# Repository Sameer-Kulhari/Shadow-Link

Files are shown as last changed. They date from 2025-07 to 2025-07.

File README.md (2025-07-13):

# Shadow-Link
A diy high performance Transmitter Module with ELRS support and custom hardware which can transmit data using Sx1280 RF module and ESP-32.
This Transmitter module works on a open source Firmware called ELRS ,which is used in high end transmitters and recievers

# Features :
- 15km + range (LOS)
- 5ms latency
- Oled and RGB
- External Antenna
- ELRS support
- Custom case and Pcb
- Works on Uart
- Works with any ELRS reciever

# Purpose :
- I made this transmitter module for my future projects in which they need a device to transfer data wirelessly , for long range and quickly ,So i made this transmitter module,So I can just send data to this module via Uart and receive on other side using any ELRS reciever.

# Parts Used :
- ESP-32 WROOM
- E28-2G4M27S (SX1280)
- NEOPIXEL (WS2812)
- 0.96" I2C SSD1306
- MP1584 Step Down Regulator

# Images :
**PCB :**
<p align="center">
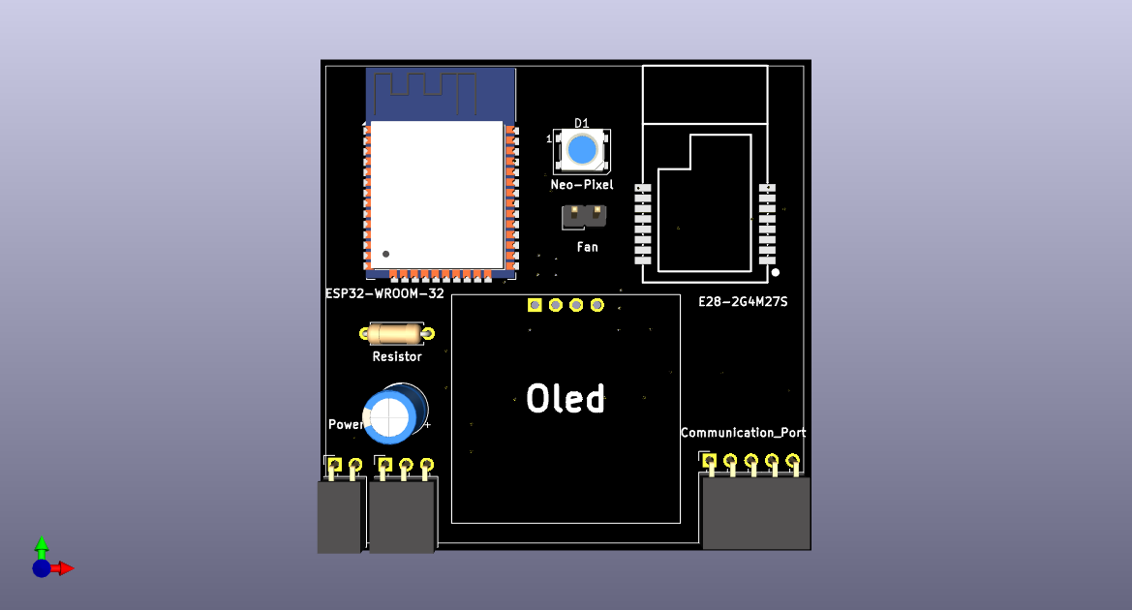
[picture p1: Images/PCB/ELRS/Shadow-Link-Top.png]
  
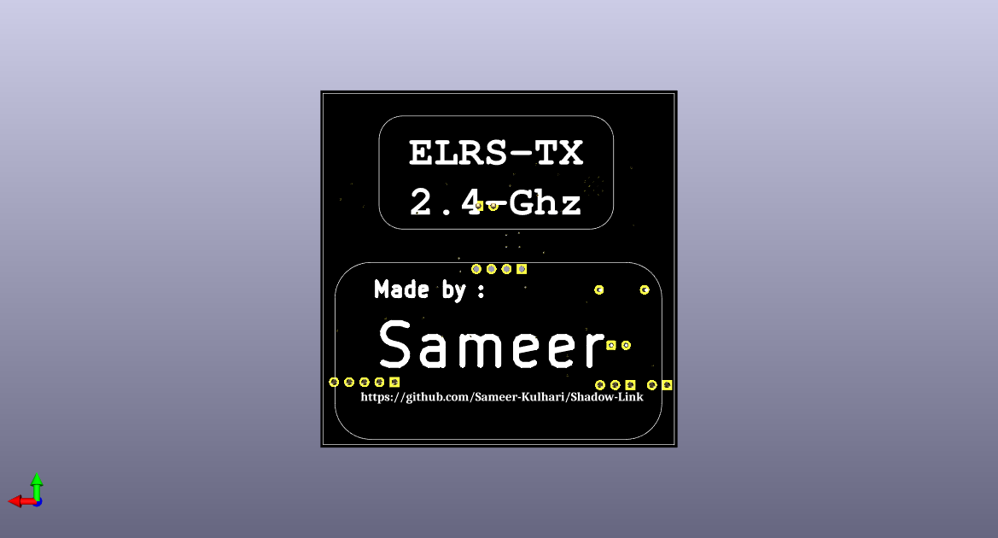
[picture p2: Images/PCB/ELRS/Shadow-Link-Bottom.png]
  
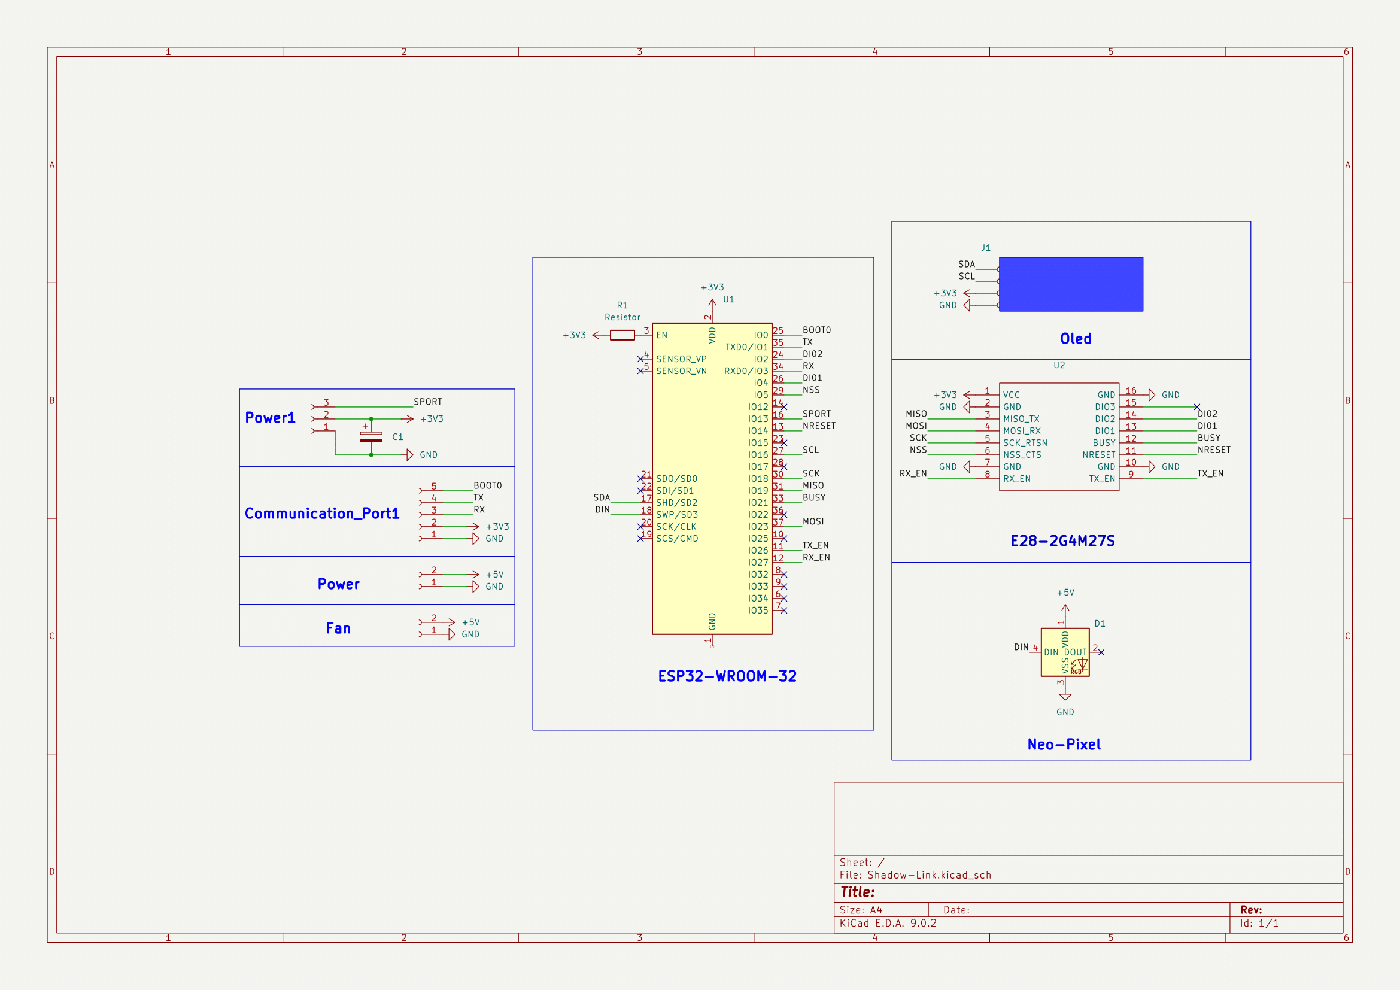
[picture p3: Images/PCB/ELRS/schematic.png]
  
</p>

**CAD :**
<p align="center">
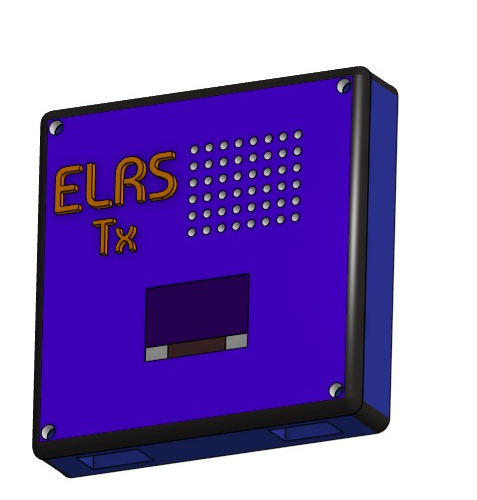
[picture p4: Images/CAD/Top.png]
  
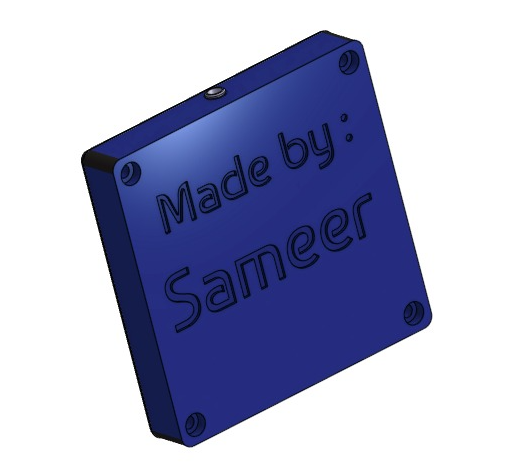
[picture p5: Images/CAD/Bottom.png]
  
</p>

# BOM :
| Supplier | Item | Price (USD) |
|---|---|---|
| **Quartz Components**| Oled SSD1306 | $1.60 |
| | MP1584 Voltage Regulator | $0.50 |
| | RG81 Ipex to SMA | $0.50 |
| | 12 dbi Antenna | $2.10 |
| | Usb to TTl converter | $0.70 |
| | Colling Fan | $0.84 |
| | Battery | $3.26 |
| | Misc | $2.00 |
| | Shipping | $2.54 |
| | **Total (Quartz Components)** | **$13.94**  |
| **Lion Circuits** | PCB | $11.54 |
| | Shipping | $2.33 |
| | **Total (Lion Circuits)** | **$13.87**  |
| **SemiNest** | E28-2G4M27S | $16.9 |
| | ESP32-WROOM-32E-N16 | $8.85 |
| | Shipping | $2.33 |
| | **Total (SemiNest)** | **$28.08**  |
|----------------------|------------------------------------------------|-------------|
|**Total** | | **$55.89**  |

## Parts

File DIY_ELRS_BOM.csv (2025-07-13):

Supplier | Item | Price (USD) | Link
Quartz Components | OLED SSD1306 | 1.6 | https://quartzcomponents.com/products/oled-display-0-96-inch-i2c-interface-4-pin-blue-ssd1306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
Quartz Components | MP1584 Voltage Regulator | 0.5 | https://quartzcomponents.com/products/ultra-small-size-dc-dc-step-down-power-supply-module-3a-adjustable-buck-converter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
Quartz Components | RG81 Ipex to SMA | 0.5 | https://quartzcomponents.com/products/rg81-ipx-to-sma-female-rf-cable-10cm?variant=45037619904746
Quartz Components | 12 dBi Antenna | 2.1 | https://quartzcomponents.com/products/2-4ghz-5g-12dbi-dual-band-wifi-antenna-with-rp-sma-male-connector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
Quartz Components | USB to TTL Converter | 0.7 | https://quartzcomponents.com/products/ch340g-usb-to-ttl-converter?variant=39261305602232
Quartz Components | Cooling Fan | 0.84 | https://quartzcomponents.com/products/raspberry-pi-cooling-fan?variant=31897905365127
Quartz Components | Battery | 3.26 | https://quartzcomponents.com/products/3-7v-4400mah-lithium-battery-with-1-year-warranty?variant=43584594084074
Quartz Components | Misc | 2
Quartz Components | Shipping | 2.54
Quartz Components | TOTAL | 13.94
Lion Circuits | PCB | 11.54 | https://order.lioncircuits.com/
Lion Circuits | Shipping | 2.33
Lion Circuits | TOTAL | 13.87
SemiNest | E28-2G4M27S | 16.9 | https://seminest.in/shop/iot-communication-modules/lora-modules/chengdu-ebyte-elec-tech-e28-2g4m27s/
SemiNest | ESP32-WROOM-32E-N16 | 8.85 | https://seminest.in/shop/iot-communication-modules/wifi-modules/espressif-systems-esp32-wroom-32e-n16/
SemiNest | Shipping | 2.33
SemiNest | TOTAL | 28.08
 |  | Total | 55.89

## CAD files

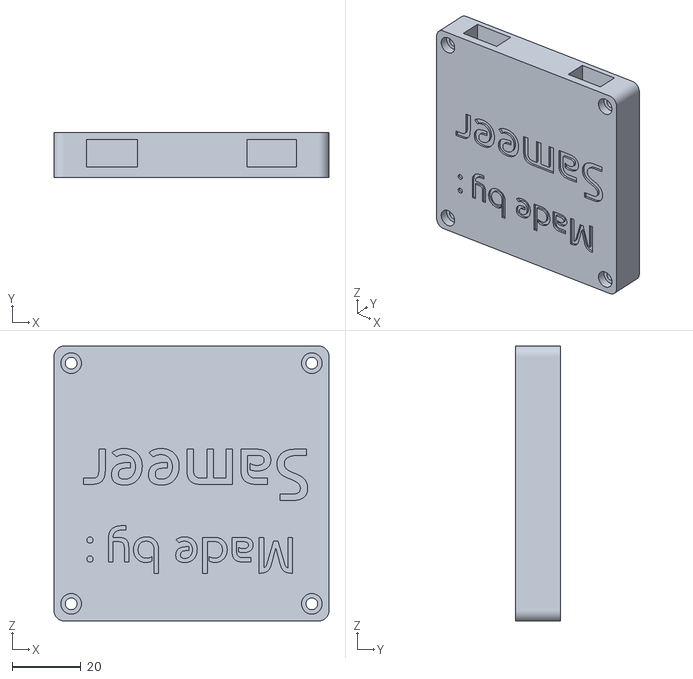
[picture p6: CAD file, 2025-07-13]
CAD/Bottom.stl
80.0 x 13.0 x 80.0

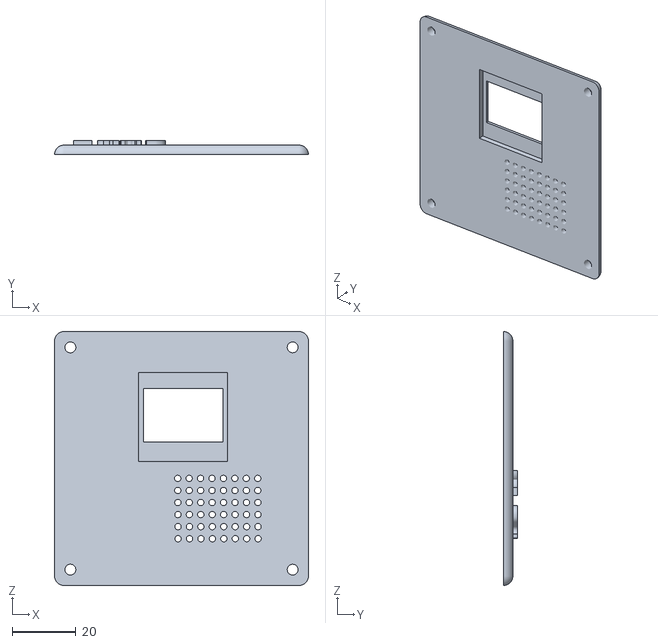
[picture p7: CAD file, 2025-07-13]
CAD/Top.stl
80.0 x 4.50 x 80.0

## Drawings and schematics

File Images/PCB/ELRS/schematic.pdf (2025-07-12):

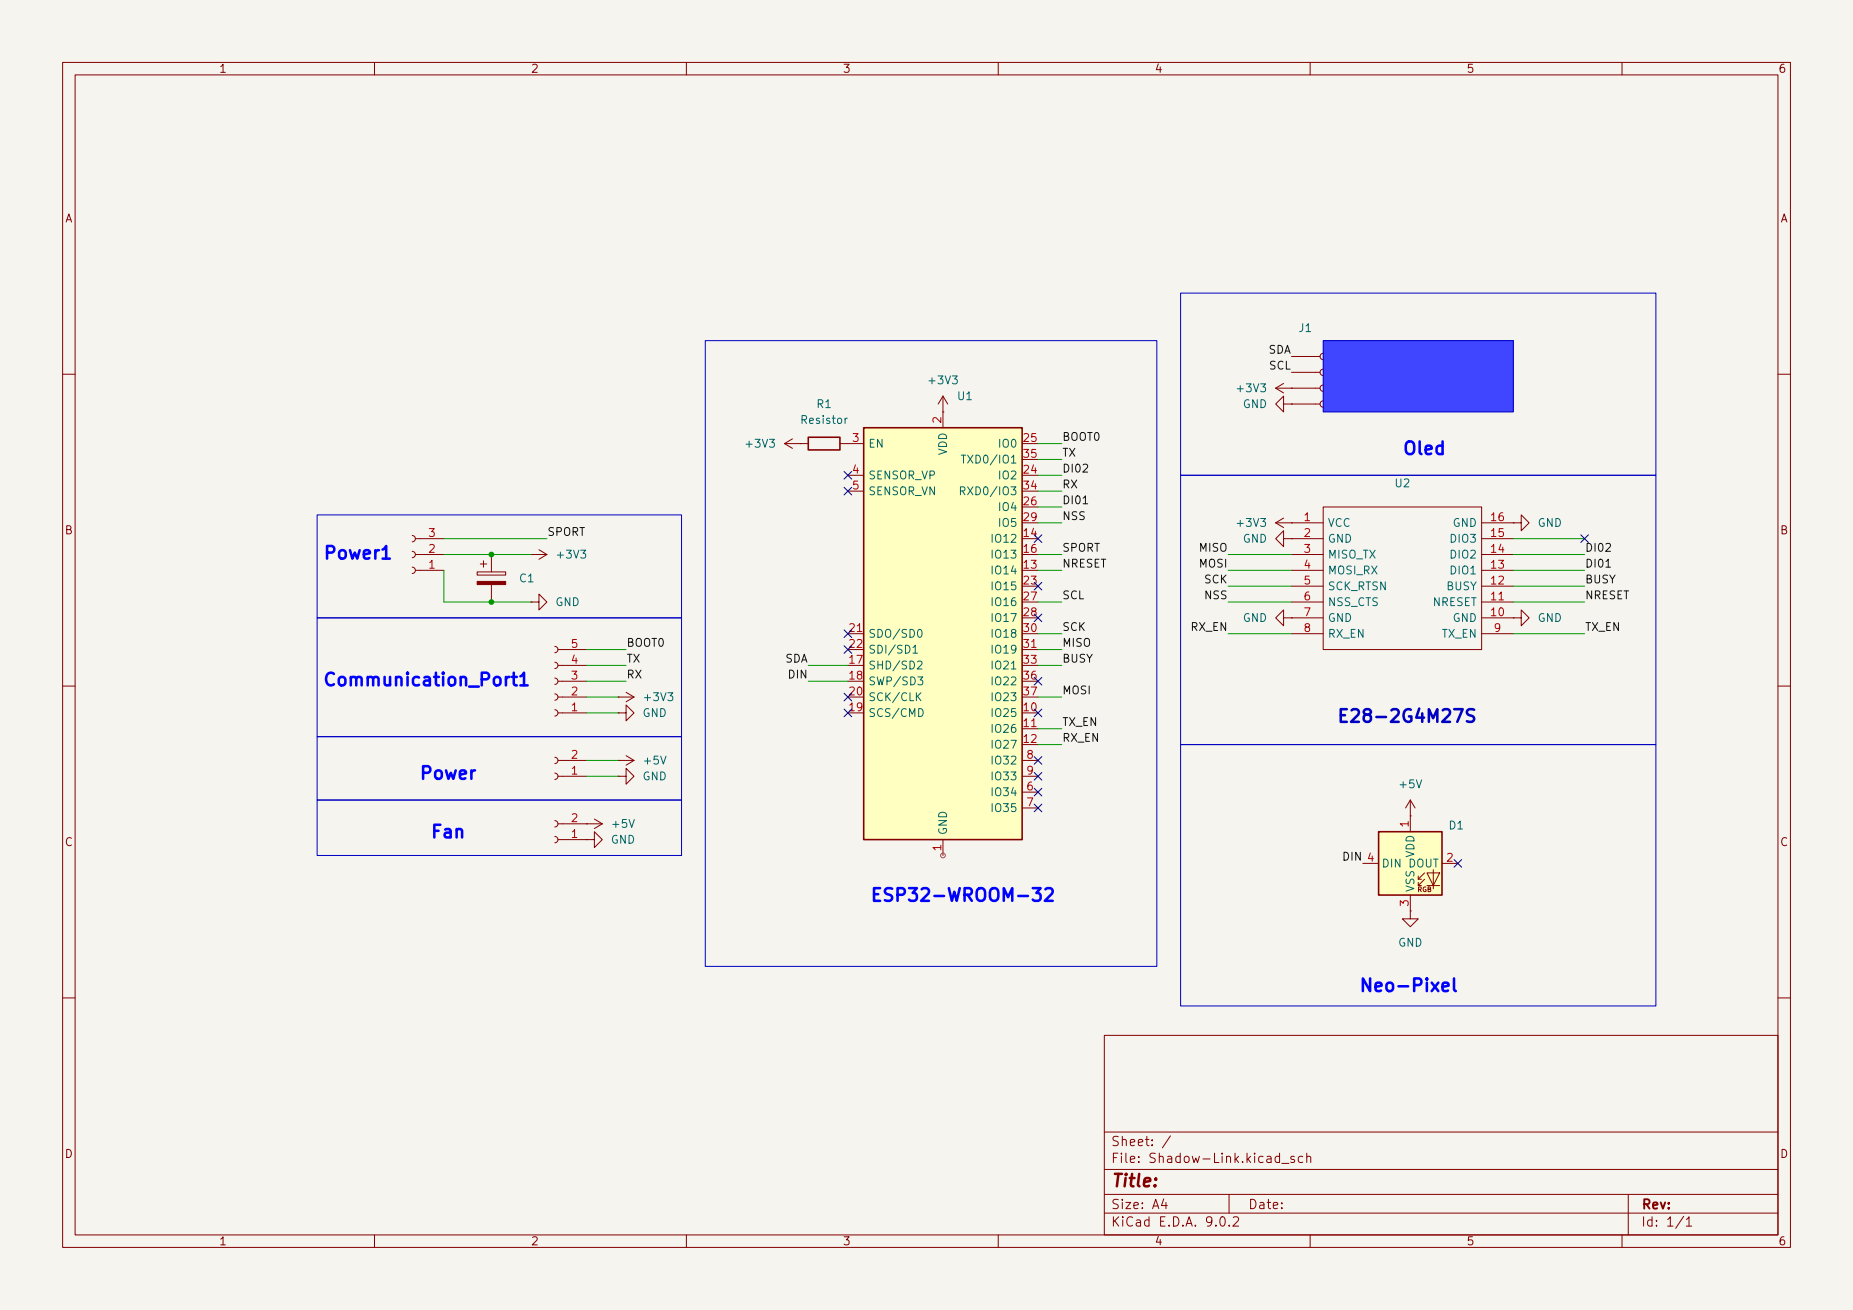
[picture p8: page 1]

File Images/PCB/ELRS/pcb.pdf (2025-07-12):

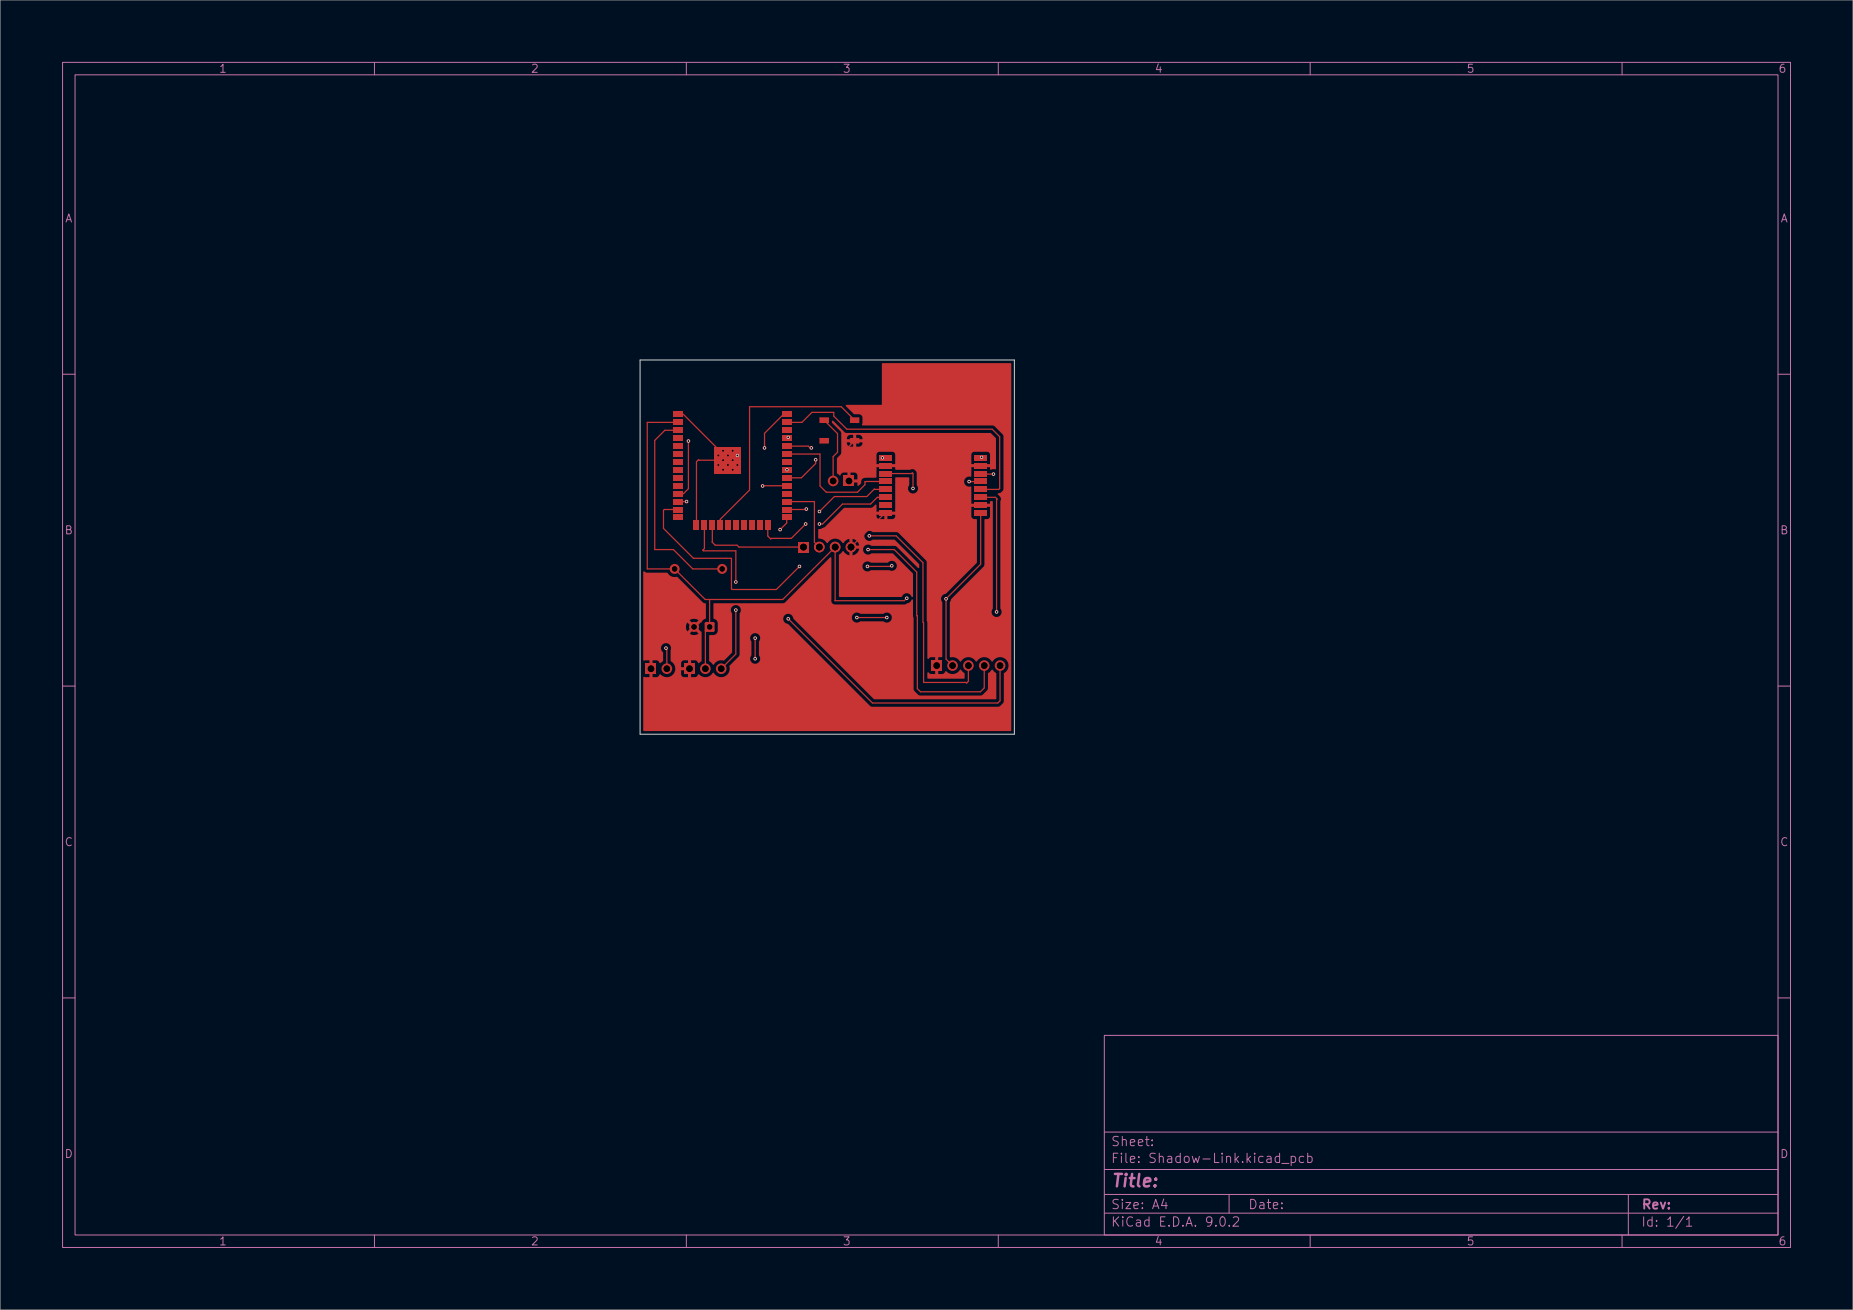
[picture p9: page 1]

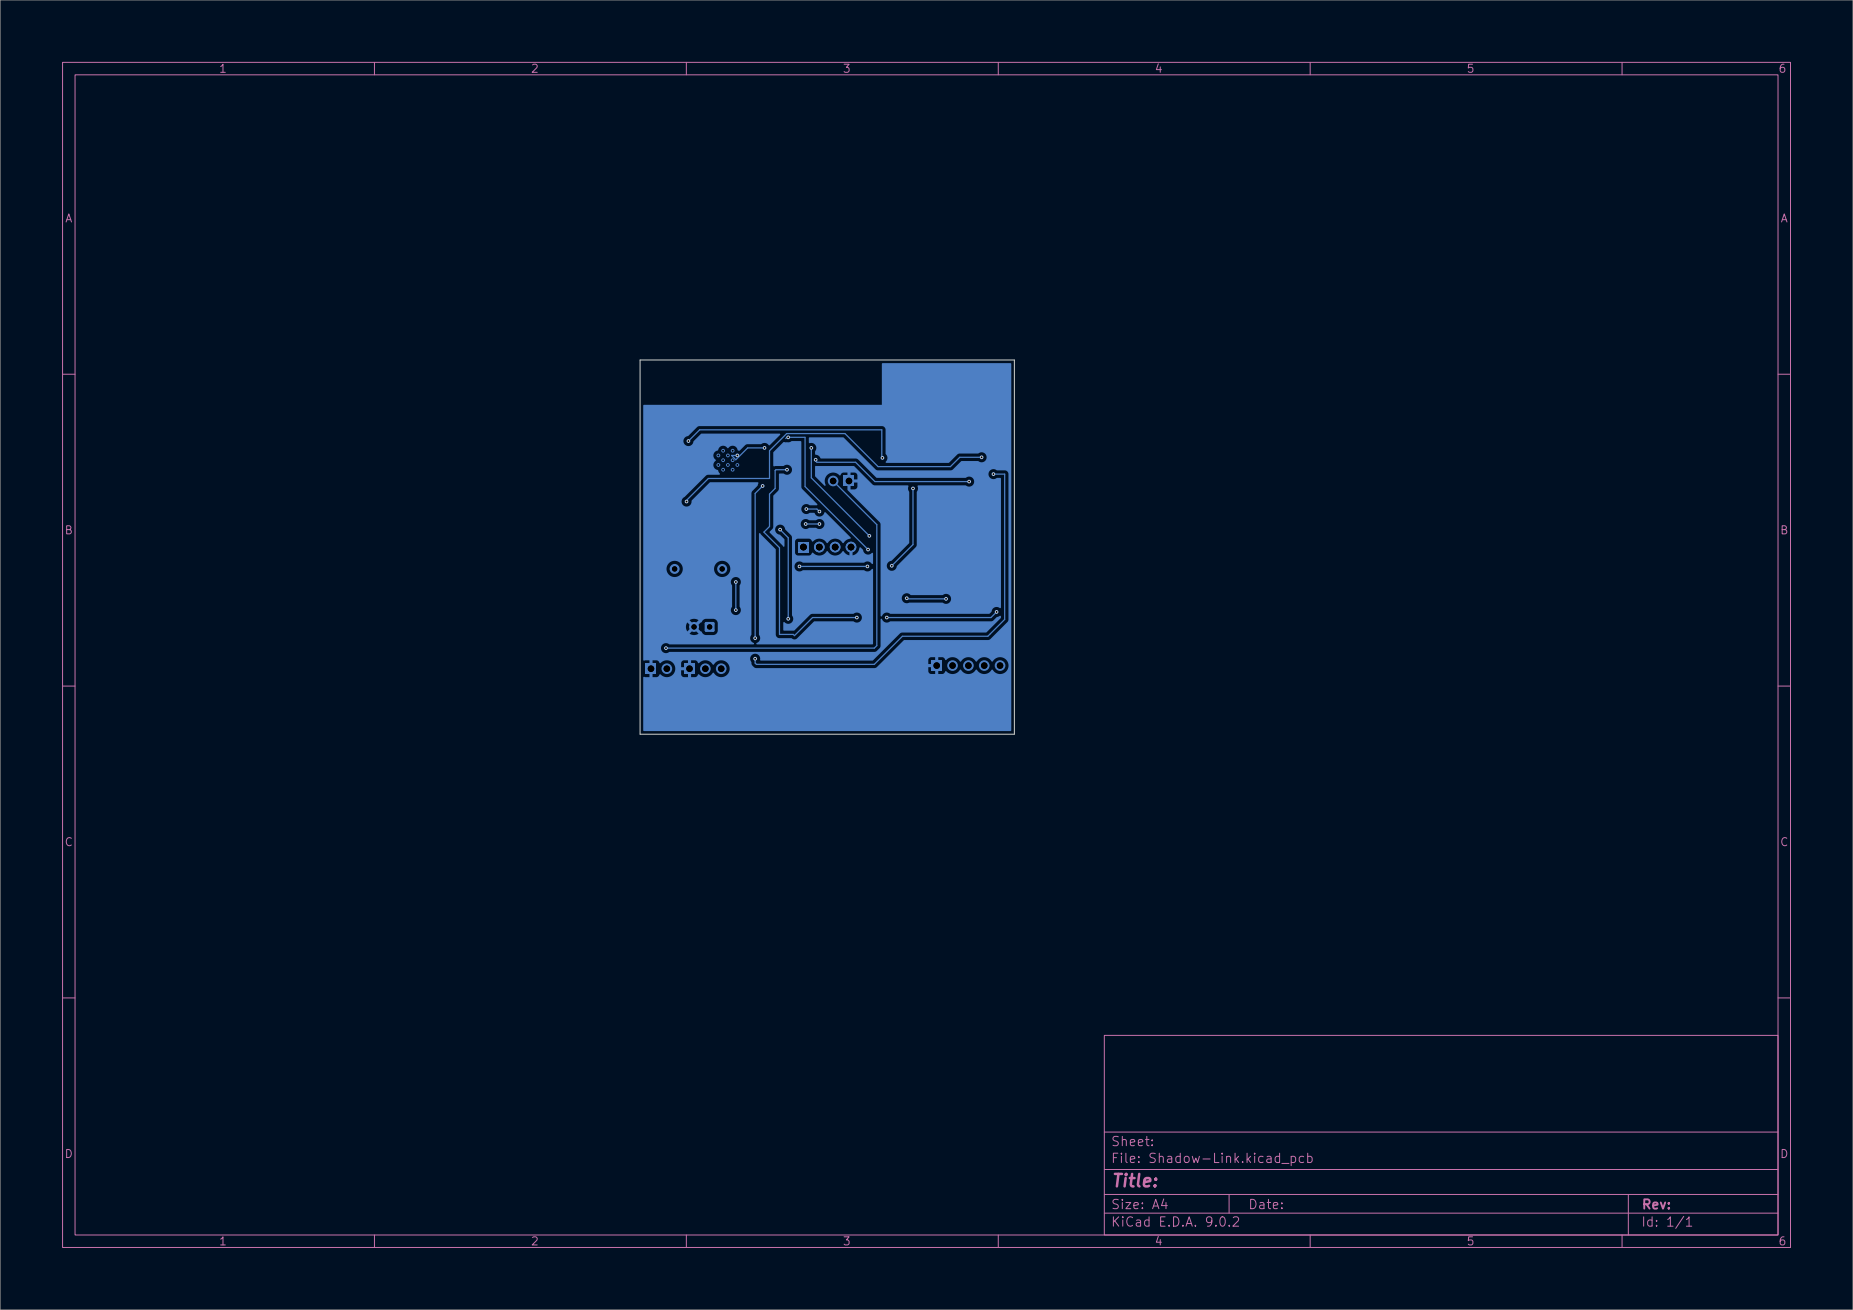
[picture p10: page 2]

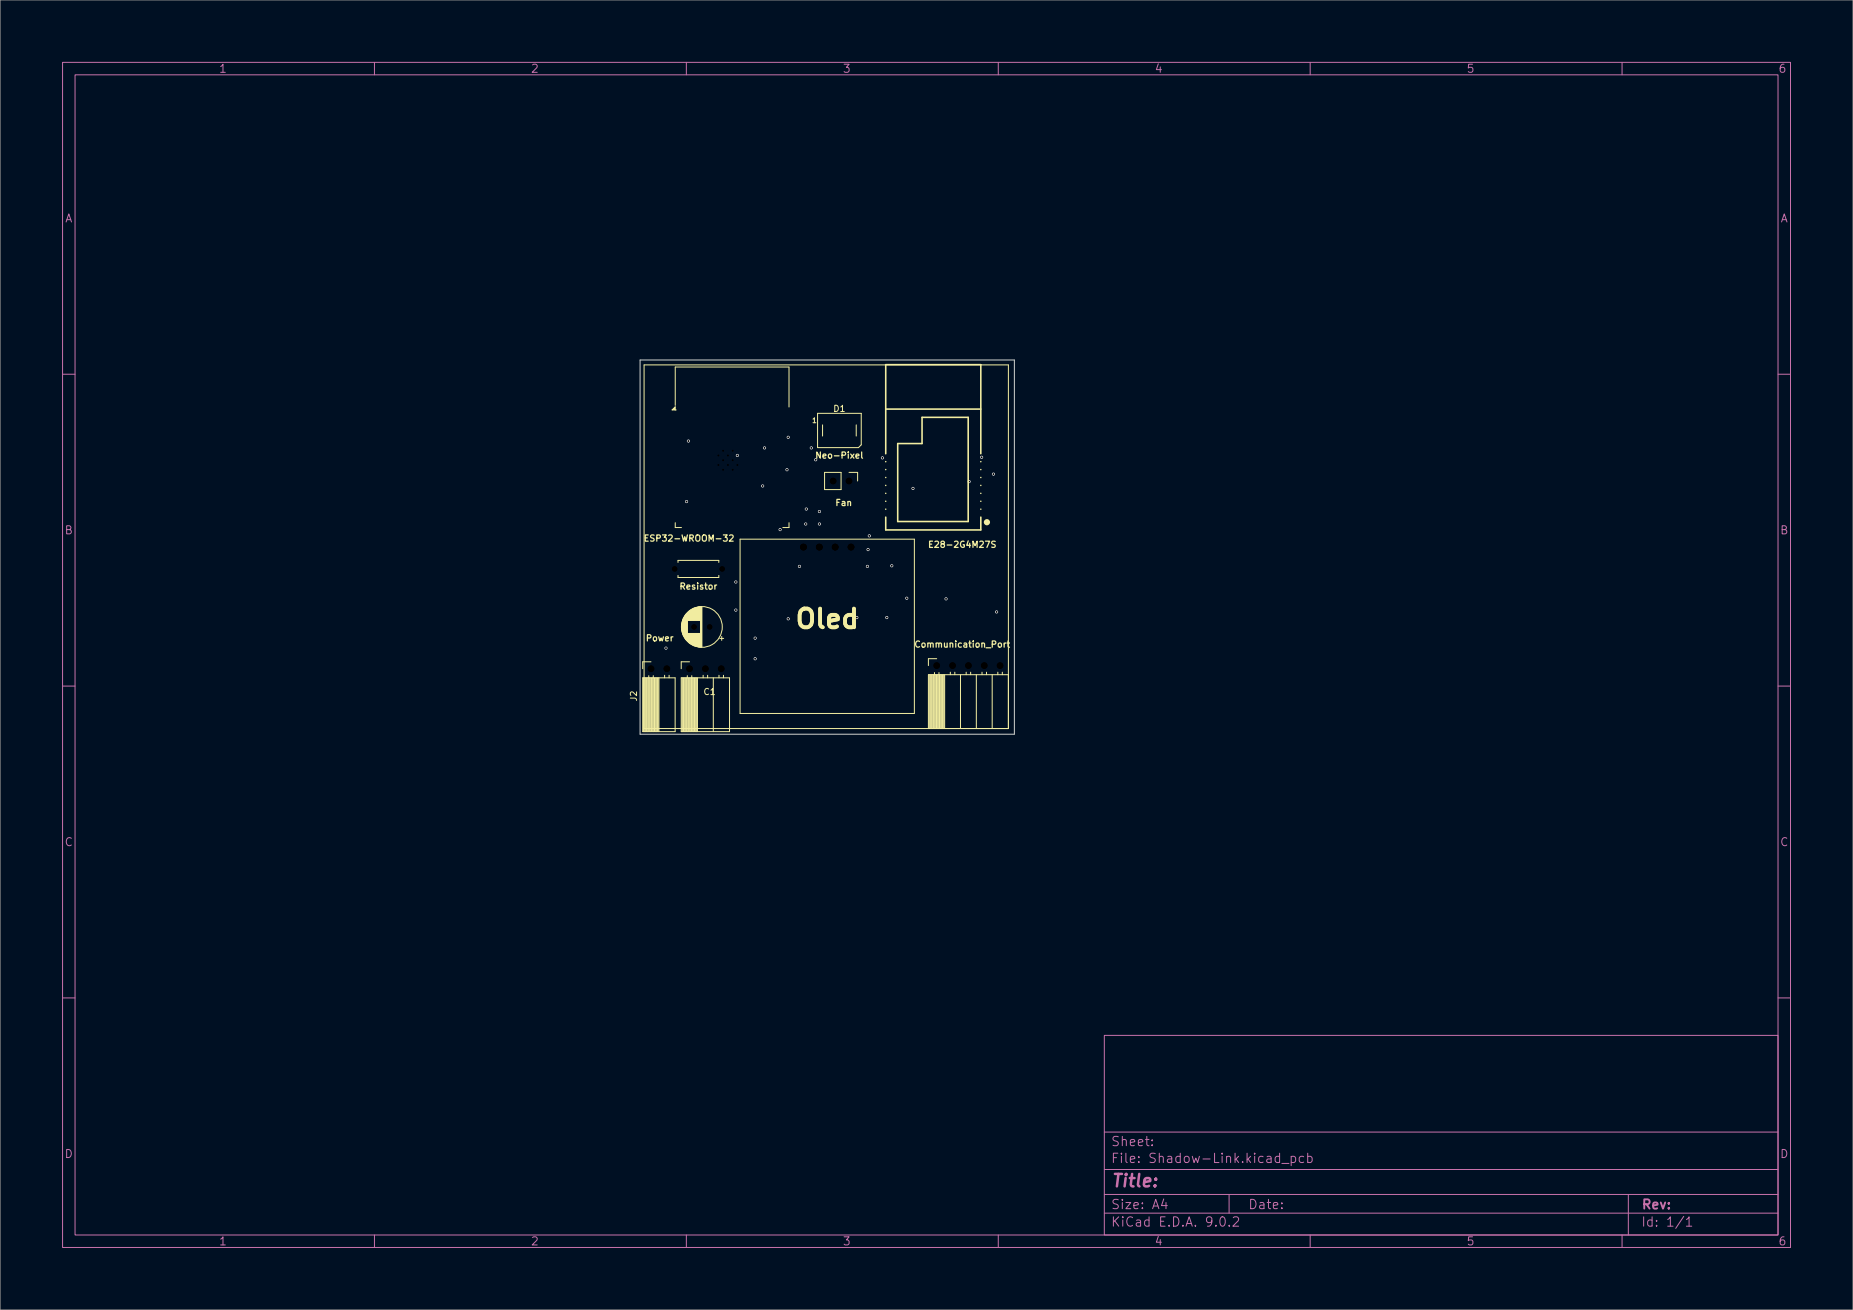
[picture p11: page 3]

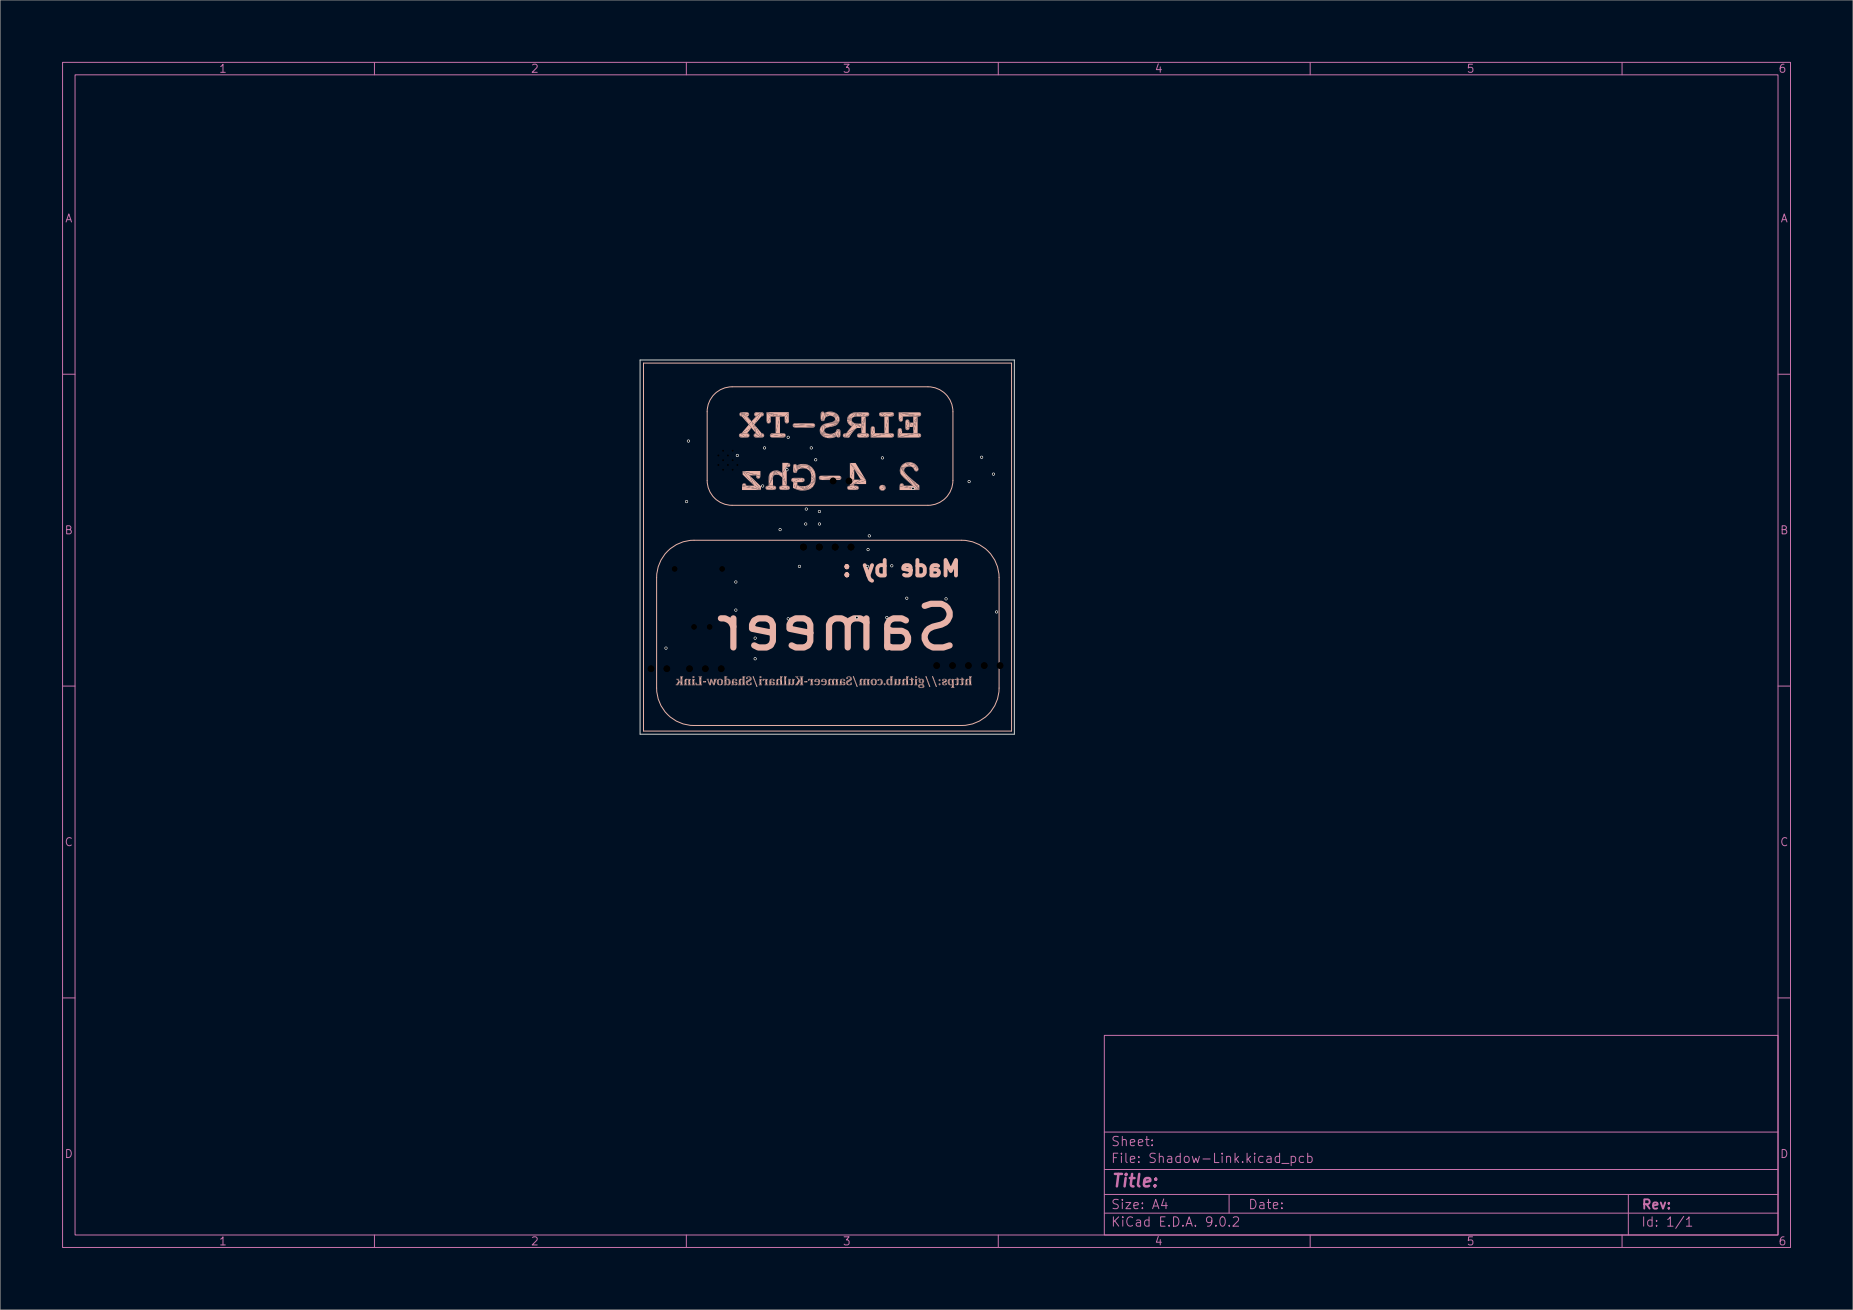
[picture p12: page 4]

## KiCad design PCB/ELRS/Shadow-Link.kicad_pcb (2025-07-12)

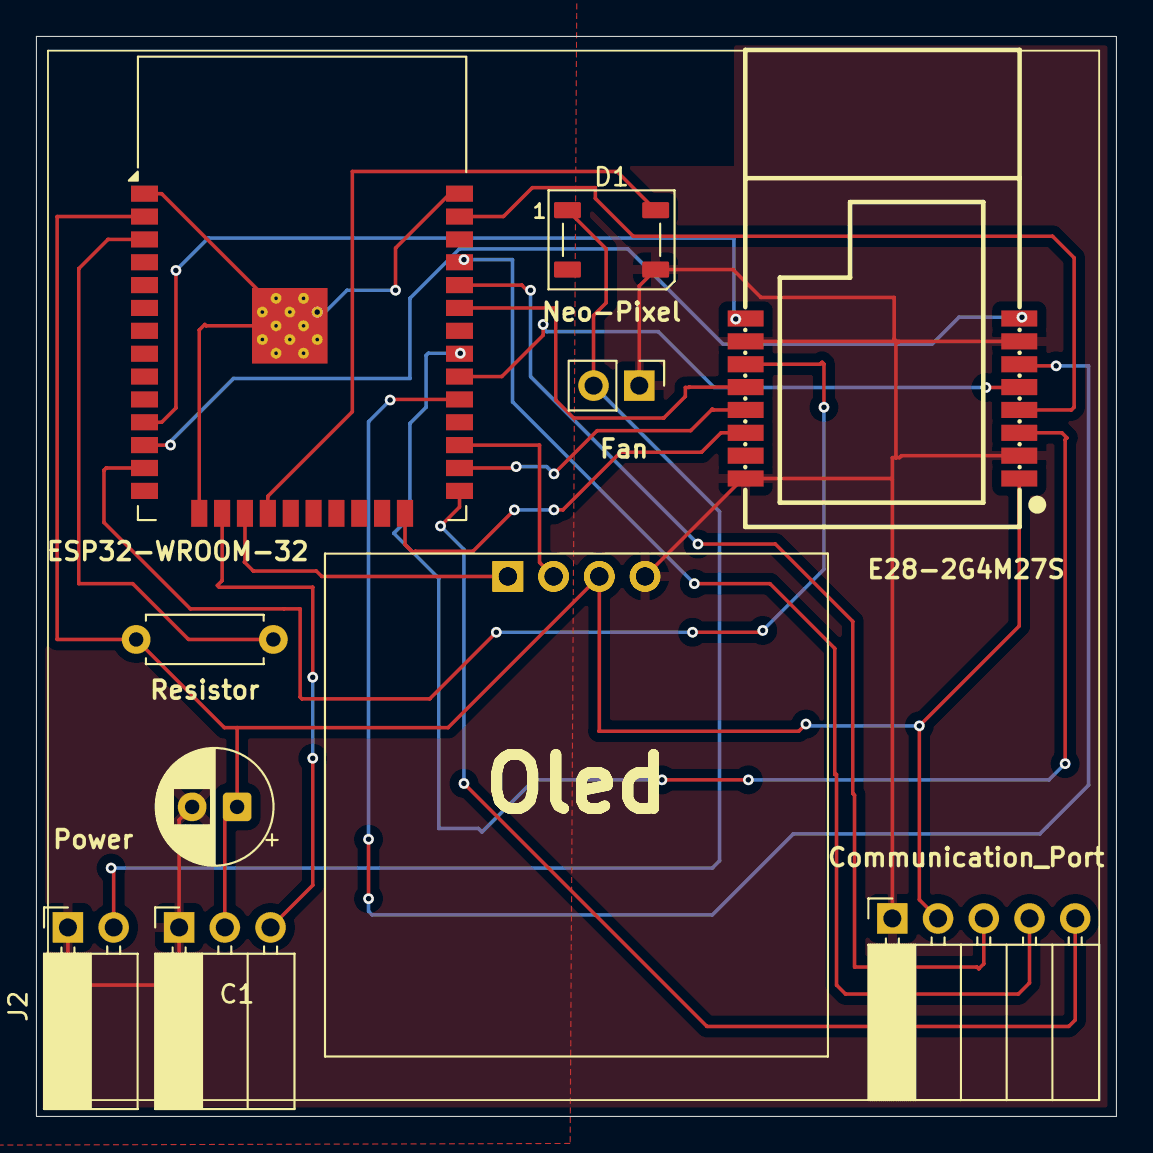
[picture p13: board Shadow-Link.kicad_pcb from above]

Board: 2 copper layers, 60.0 x 60.0 mm, 11 parts (0 on the bottom side), 22 nets.

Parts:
C1: C_Polarized; CP_Radial_D6.3mm_P2.50mm
Communication_Port: Conn_01x05_Socket; PinSocket_1x05_P2.54mm_Horizontal
D1: Neo-Pixel; LED_WS2812B_PLCC4_5.0x5.0mm_P3.2mm
J1, J1#2: Oled; OLED_128x64
J2: Power; PinSocket_1x02_P2.54mm_Horizontal
J3: Fan; PinHeader_1x02_P2.54mm_Vertical
Power: Conn_01x03_Socket; PinSocket_1x03_P2.54mm_Horizontal
R1: Resistor; R_Axial_DIN0207_L6.3mm_D2.5mm_P7.62mm_Horizontal
U1: ESP32-WROOM-32
U2: WIRELM-SMD_E28-2G4M2XS

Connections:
+3V3: C1.1, Communication_Port.2, J1.3, J1#2.3, Power.2, R1.1, U1.2 (VDD), U2.1 (VCC)
+5V: D1.1 (VDD), J2.2, J3.2
/BOOT0: Communication_Port.5, U1.25 (IO0)
/BUSY: U1.33 (IO21), U2.12 (BUSY)
/DI01: U1.26 (IO4), U2.13 (DIO1)
/DI02: U1.24 (IO2), U2.14 (DIO2)
/DIN: D1.4 (DIN), U1.18 (SWP/SD3)
/MISO: U1.31 (IO19), U2.3 (MISO_TX)
/MOSI: U1.37 (IO23), U2.4 (MOSI_RX)
/NRESET: U1.13 (IO14), U2.11 (NRESET)
/NSS: U1.29 (IO5), U2.6 (NSS_CTS)
/RX: Communication_Port.3, U1.34 (RXD0/IO3)
/RX_EN: U1.12 (IO27), U2.8 (RX_EN)
/SCK: U1.30 (IO18), U2.5 (SCK_RTSN)
/SCL: J1.2, J1#2.2, U1.27 (IO16)
/SDA: J1.1, J1#2.1, U1.17 (SHD/SD2)
/SPORT: Power.3, U1.16 (IO13)
/TX: Communication_Port.4, U1.35 (TXD0/IO1)
/TX_EN: U1.11 (IO26), U2.9 (TX_EN)
GND: C1.2, Communication_Port.1, D1.3 (VSS), J1.4, J1#2.4, J2.1, J3.1, Power.1, U2.2 (GND), U2.7 (GND), U2.10 (GND), U2.16 (GND)
unnamed: R1.2, U1.3 (EN)
unnamed: U1.1 (GND), U1.15 (GND), U1.38 (GND), U1.39 (GND)

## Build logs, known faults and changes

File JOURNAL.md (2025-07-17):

---
Title: "Shadow-link"
Author: "Sameer-Kulhari"
Description: "A transmitter module with ELRS support that can transmit data to 1
15+km "
Created_at: "2025-07-09"
---
**Total Time Spent : 24hr**
---

# Project Journal – DIY ELRS Transmitter Module  
**By Sameer Kulhari**

## June 8th: Designed the idea and working of the project

Today, I figured out the full concept of how my transmitter module will actually work and how I can build it from scratch. I spent a lot of time researching how professional transmitters like **Radiomaster**, **Jumper**, and **Flysky** are built and what features they have.

One cool thing I found is that most of the mid to high-end transmitters support **ExpressLRS (ELRS)** — which is open-source! That was a big moment because it means I could also use ELRS in my own DIY transmitter module.

After all the research, I now had a clear idea of what I wanted to make — how the transmitter will function, what components it’ll need, and even how it should look. I drew the full plan on paper.

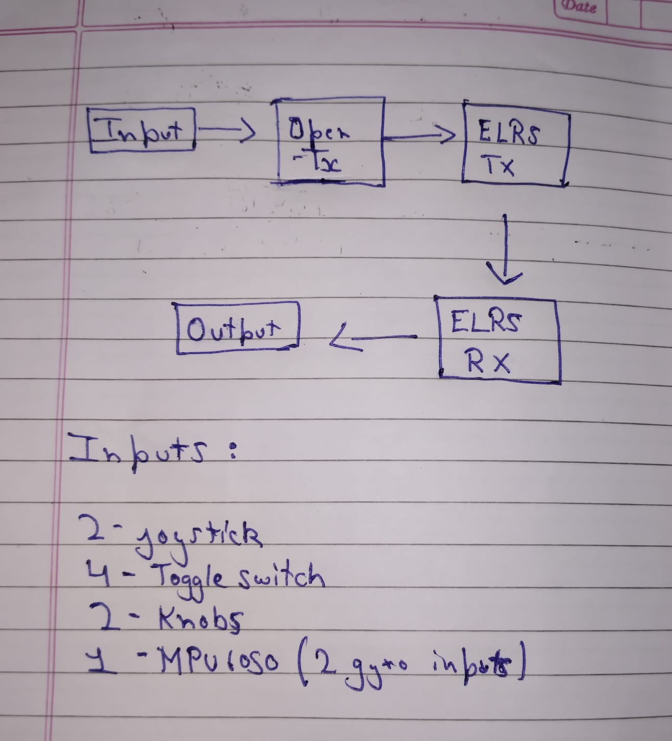
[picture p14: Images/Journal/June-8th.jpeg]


**Total time spent: 4.5 hours**

---

##  June 9th: Designed the schematic and PCB for ELRS-TX

Today I moved from planning to actually designing. I used **KiCad** to create the full schematic and layout for my **ELRS-TX** board.

Once the PCB was ready, I exported the **gerber files**, added all the **libraries**, and uploaded **layer images** and a **3D view** of the PCB to my GitHub repository so everything stays well-documented and reproducible.

**Here are a few images from the repo:**

<p align="center">
  
  
</p>

**Total time spent: 3.5 hours**

---

## June 10th: Updated PCB and added new parts for ELRS-TX

Today I focused on upgrades and made the board even better!

I first created a list of new components that I could add to make the transmitter feel more pro-level. After that, I updated the schematic with these parts and redesigned the PCB to make it **modular** — so the ELRS-TX board can be plugged in easily and used as a **plug-and-play module**.

### New features I added:
-  **Cooling fan** for stable performance
-  **NeoPixel** for status indication
-  **New power input option**

The final schematic looks clean, and the new board layout is compact and efficient.



**Total time spent: 4 hours**

---

##  June 12th: Started designing the case

Today I worked on the outer casing of the transmitter. I took all the dimensions from the PCBs and components and then used **Onshape** to start designing the case.

It’s still in the prototyping stage, but the fit looks really good!

Here are some preview pics:

<p align="center">
  
  
</p>

**Total time spent: 5 hours**

---

## June 13th: Parts sourcing + README update

I researched and finalized where to buy all the components — including the ESP32, E28 LoRa module, OLED, and other parts.

After that, I updated the **README file** and this **journal log** to include all the new changes and features I’ve added over the last few days.

Now the project is fully documented and ready to share! 

**Total time spent: 3 hours**

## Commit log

2025-07-09 June 9th
    [ELRS.kicad_pcb, ELRS.kicad_sch]
2025-07-12 New Version
    [ELRS.kicad_pcb, ELRS.kicad_sch]
2025-07-12 Updated version
    [Shadow-Link.kicad_pcb, Shadow-Link.kicad_sch]
2025-07-13 3d Model Added
    [Bottom.stl, Top.stl]
2025-07-13 Uploaded Schematic
2025-07-13 Added BOM
    [DIY_ELRS_BOM.csv]
